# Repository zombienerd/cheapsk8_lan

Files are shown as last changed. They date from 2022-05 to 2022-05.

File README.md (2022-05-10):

CheapSk8 LAN is an 8-bit ISA network card based on the RTL 8019AS chip.  

This project was created for cost savings over purchasing older cards on eBay or building other similar projects.  This project was done by reverse engineering a 16-bit RTL8019AS board, and finding the bits needed in the datasheet to turn off 16 bit mode.

By sourcing the MagJack and RTL8019AS from Aliexpress, the 93LC46 from eBay, and the discretes from Mouser or Digikey, and the PCB from JLCPCB, the bill of materials for a board is only about $7.50 when you build 20 or more.

Link to MagJacks: https://www.aliexpress.com/item/32845892783.html

Link to RTL8019AS: https://www.aliexpress.com/item/4000545658898.html

Link to 93LC46 SMT 1k PROM: https://www.ebay.com/itm/133483822518

Mouser-bom.ods is a spreadsheet for the other discretes needed once you've sourced the above 3 items.

Entire project is licensed under CC BY-SA 4.0: https://creativecommons.org/licenses/by-sa/4.0/  You may copy/modify/distribute this project as you see fit as long as my name and project name are listed, and the license is carried forward to your project.

Drivers / Configuration:

In the Drivers/Config folder, you will find the following software:

NE2000.COM - Modified Crynwr Packet Driver for 8-bit NE2000 based cards.  Modified by Dan over on the VCF Forums (https://forum.vcfed.org/index.php?threads/ne2000-packet-drivers-for-8-bit-slots.41507/)
NE2000.ASM - Associated file to NE2000.COM
PG9018.EXE - Initial programming tool for the card.
8019AS.CFG - Initial Configuration file for the card (Read ahead carefully)
RSET8019.EXE - Configuration tool for the card.

Before configuration, edit 8019AS.CFG and add a MAC address to the 1st line.  If you are building more than one card, you should ensure that no two cards have the same address.  You can use one of the Private MAC address Allocations, known as "Locally Administered Address Ranges" and will not be used by mainstream devices or vendors. The MAC addresses in these ranges can be safely used, as long as they are unique within your network:

x2-xx-xx-xx-xx-xx

x6-xx-xx-xx-xx-xx

xA-xx-xx-xx-xx-xx

xE-xx-xx-xx-xx-xx

Each pair can be any hexadecimal number. You use space instead of - in the cfg file.  For example:  52 0a 1b 3c 4e 5f 00 or 12 1a 2b 3c 4d 5e

You should set your IOBASE to a free IO address (300 is default), IRQ (2 is default), and enable or disable the bootrom.  Beware conflicts with XT-IDE, or certain Sound Card/Midi Devices.  

Once you have edited the file to your liking, boot your machine with no memory managers (EMM386 or HIMEM.sys) and run PG8019.EXE  - this will program the card and tick up the MAC address and serial number incrementally in the 8019as.cfg file, so you don't have to edit to run it on subsequent cards.

Once the card is programmed, you can use RSET8019.EXE at any time to change the Base address and IRQ if you plan to change your system configuration.

Thank you to Sergey Kiselev for hosting the 8019 programming tools that I have copied over for this project.  Check out his very similar project (that's a lot more polished, and a bit more high class) over at https://github.com/skiselev/isa8_eth

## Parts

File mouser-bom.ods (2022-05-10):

SHOPPING CART
This is not an invoice
09-May-22 19:49:48
 | Mouser # | Mfr. # | Manufacturer | Description | Order Qty. | Price (USD) | Ext.: (USD)
1 | 774-ATS200C | ATS200-C | CTS | Crystals 20MHz 18pF Fund. -20C +70C | 20 | $0.30 | $6.00
2 | 77-VJ0603A100JXACBC | VJ0603A100JXACW1BC | Vishay | Multilayer Ceramic Capacitors MLCC - SMD/SMT 0603 10pF 50volts C0G 5% | 40 | $0.046 | $1.84
3 | 77-VJ0603Y103JXACBC | VJ0603Y103JXACW1BC | Vishay | Multilayer Ceramic Capacitors MLCC - SMD/SMT 0603 0.01uF 50volts X7R 5% | 40 | $0.07 | $2.80
4 | 77-VJ0603Y104JXJPBC | VJ0603Y104JXJPW1BC | Vishay | Multilayer Ceramic Capacitors MLCC - SMD/SMT 0603 0.1uF 16volts X7R 5% | 60 | $0.134 | $8.04
5 | 603-RC0603FR-13200RL | RC0603FR-13200RL | YAGEO | Thick Film Resistors - SMD 200Ohms 1/10W 0603 1% | 20 | $0.026 | $0.52
6 | 603-RC0603FR-13470RL | RC0603FR-13470RL | YAGEO | Thick Film Resistors - SMD 470 Ohms 100-200 mW 0603 1% | 40 | $0.017 | $0.68
7 | 603-RC0603FR-1327KL | RC0603FR-1327KL | YAGEO | Thick Film Resistors - SMD 27 kOhms 100-200 mW 0603 1% | 20 | $0.018 | $0.36
8 | 603-RC0603FR-101ML | RC0603FR-101ML | YAGEO | Thick Film Resistors - SMD 1 MOhms 100-200 mW 0603 1% | 20 | $0.018 | $0.36
9 | 710-860010472003 | 860010472003 | Wurth Elektronik | Aluminum Electrolytic Capacitors - Radial Leaded WCAP-ATG8 22uF 25V 20% Radial | 40 | $0.10 | $4.00
10 | 667-ERJ-3GEYJ103V | ERJ-3GEYJ103V | Panasonic | Thick Film Resistors - SMD 0603 10Kohms 5% AEC-Q200 | 20 | $0.044 | $0.88
By submitting your order you agree to these terms and conditions. (https://www.mouser.com/saleterms) |  |  |  |  |  | Merchandise: | $25.48
Prices are reflected at the date and time shown.

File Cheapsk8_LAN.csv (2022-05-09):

Source: | /home/yestergearpc/cheapsk8_lan/Cheapsk8_LAN.kicad_sch
Date: | Mon 09 May 2022 02:30:59 PM EDT
Tool: | Eeschema 6.0.2+dfsg-1
Generator: | /usr/share/kicad/plugins/bom_csv_grouped_by_value_with_fp.py
Component Count: | 21
Ref | Qnty | Value | Cmp name | Footprint | Description | Vendor
C1, | 1 | 0.1uf | C | Capacitor_SMD:C_0201_0603Metric_Pad0.64x0.40mm_HandSolder | Unpolarized capacitor
C2, C3, | 2 | 0.1uF | C | Capacitor_SMD:C_0201_0603Metric_Pad0.64x0.40mm_HandSolder | Unpolarized capacitor
C4, C5, | 2 | 10pF | C | Capacitor_SMD:C_0201_0603Metric_Pad0.64x0.40mm_HandSolder | Unpolarized capacitor
C6, C7, | 2 | 22uF | C_Polarized_Small_US | Capacitor_THT:CP_Radial_D5.0mm_P2.00mm | Polarized capacitor, small US symbol
C8, C9, | 2 | 0.01uF | C | Capacitor_SMD:C_0201_0603Metric_Pad0.64x0.40mm_HandSolder | Unpolarized capacitor
J2, | 1 | Bus_ISA_8bit | Bus_ISA_8bit | ISABUS:BUS_PC | 8-bit ISA-PC bus connector
J3, | 1 | SI-50170-F | SI-50170-F | ISABUS:BEL_SI-50170-F
R14, | 1 | 27k | R | Resistor_SMD:R_0603_1608Metric_Pad0.98x0.95mm_HandSolder | Resistor
R15, | 1 | 10k | R | Resistor_SMD:R_0603_1608Metric_Pad0.98x0.95mm_HandSolder | Resistor
R16, R17, | 2 | 470 | R | Resistor_SMD:R_0603_1608Metric_Pad0.98x0.95mm_HandSolder | Resistor
R18, | 1 | 200 | R | Resistor_SMD:R_0603_1608Metric_Pad0.98x0.95mm_HandSolder | Resistor
R19, | 1 | 1M | R | Resistor_SMD:R_0603_1608Metric_Pad0.98x0.95mm_HandSolder | Resistor
U1, | 1 | RTL8019AS | RTL8019AS | ISABUS:RTL8019AS
U2, | 1 | SST39SF040 | SST39SF040 | Package_DIP:DIP-32_W15.24mm | Silicon Storage Technology (SSF) 512k x 8 Flash ROM
U3, | 1 | 93LCxxC | 93LCxxC | Package_DIP:DIP-8_W7.62mm_SMDSocket_SmallPads | Serial EEPROM, 93 Series, with ORG Pin, 2.5V, DIP-8/SOIC-8
Y1, | 1 | 20MHz | Crystal | Crystal:Crystal_HC49-U_Horizontal | Two pin crystal

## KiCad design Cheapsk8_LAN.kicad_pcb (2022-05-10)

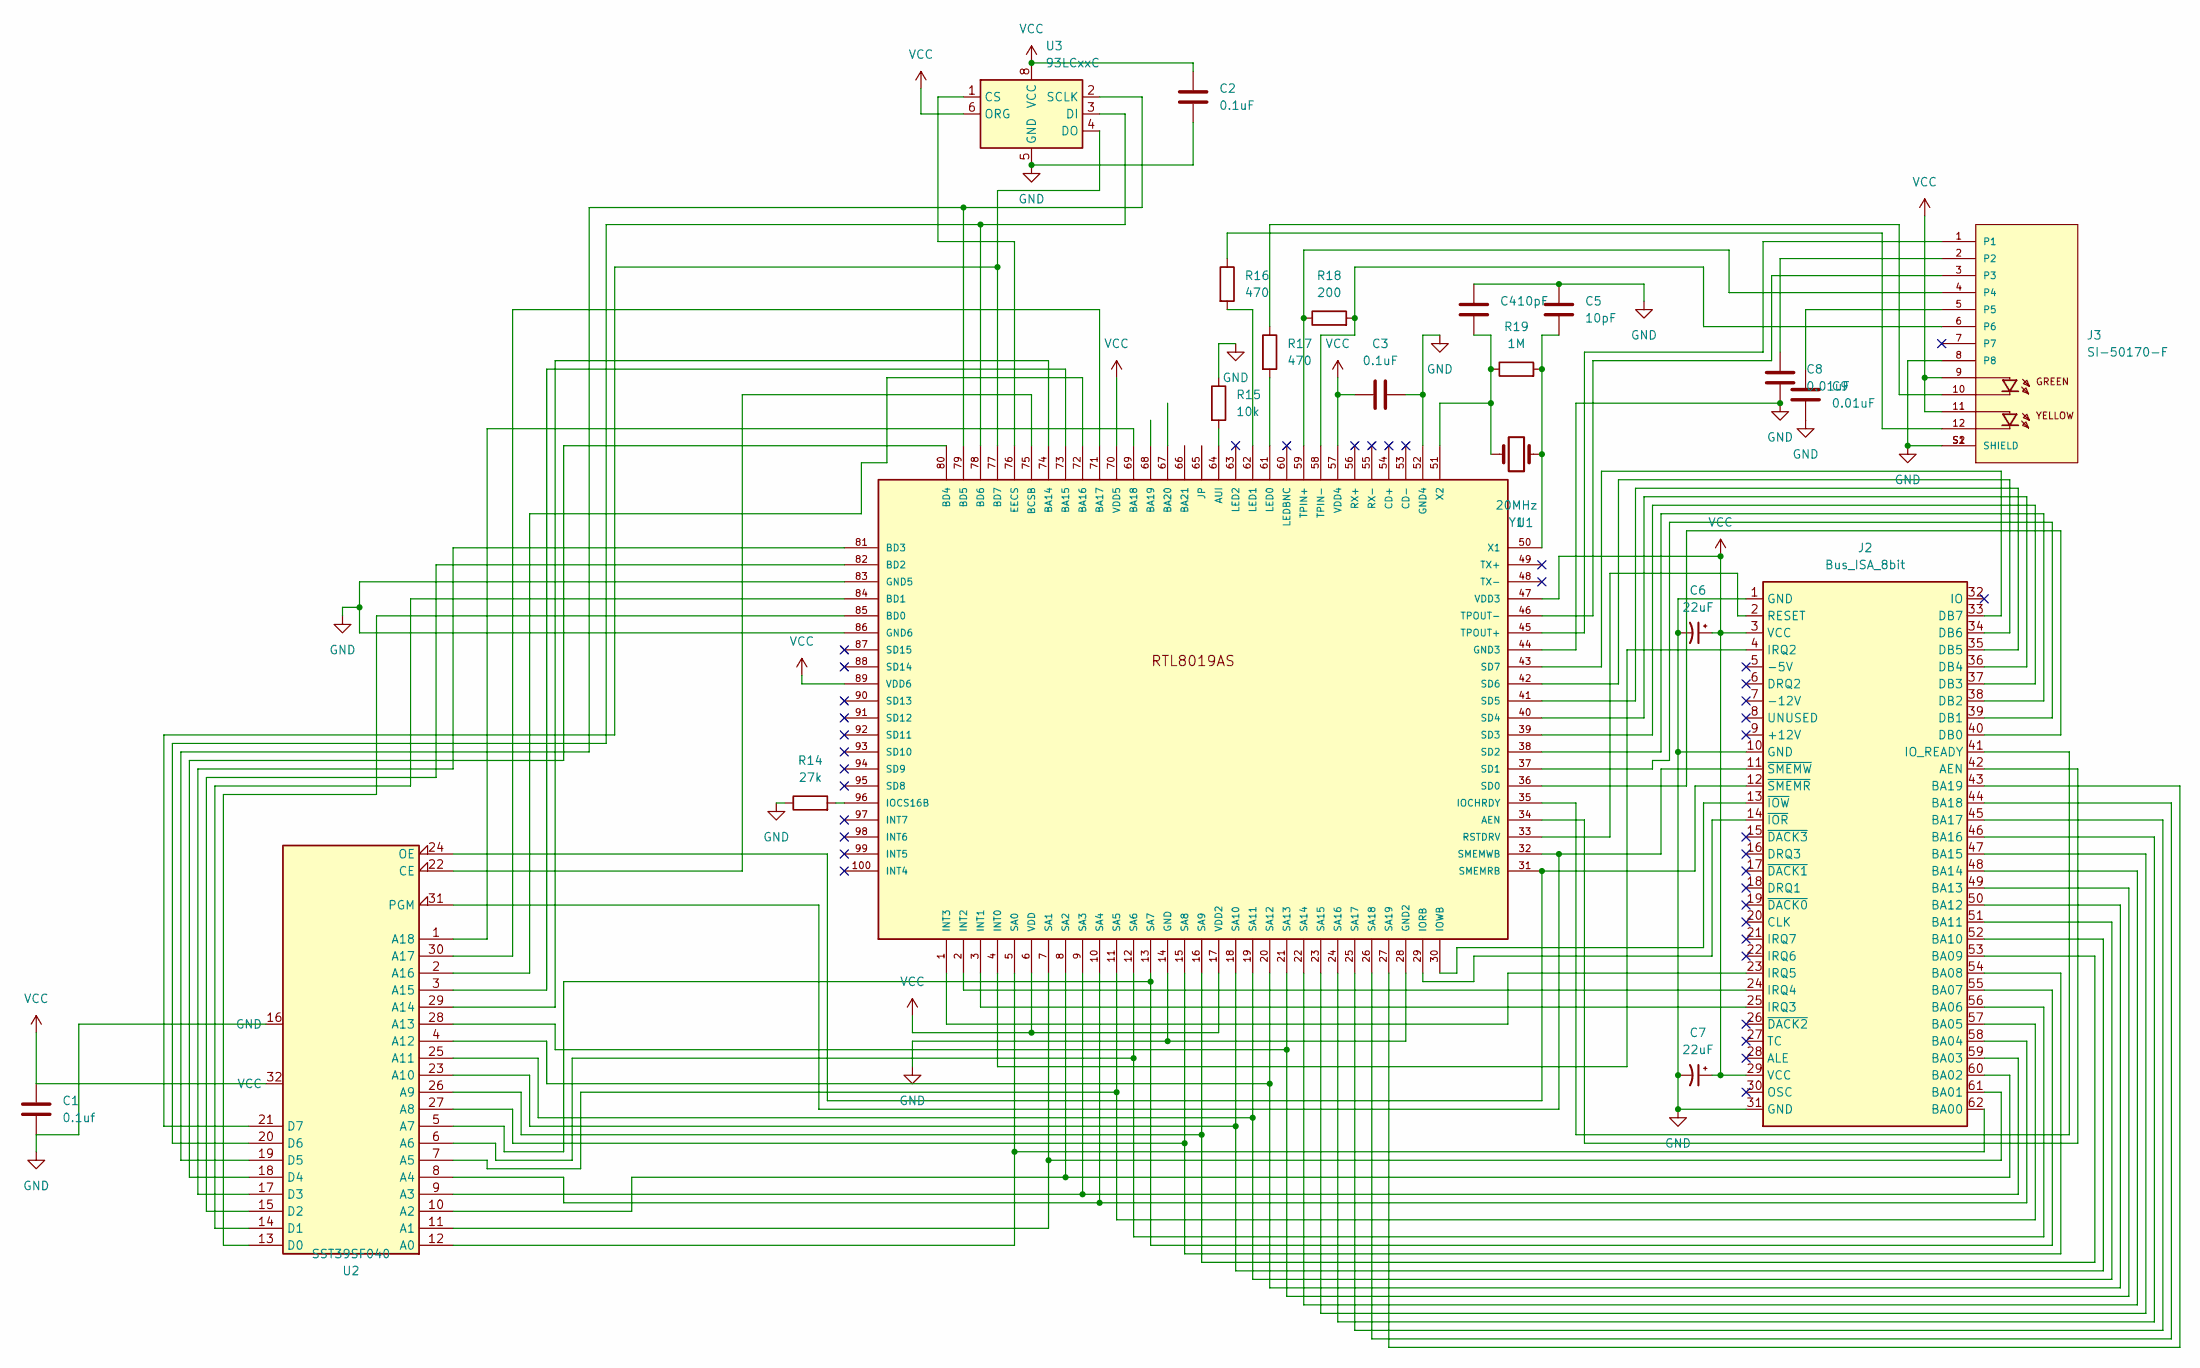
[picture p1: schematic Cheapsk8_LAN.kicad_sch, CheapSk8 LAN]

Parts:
C1: 0.1uf; C_0201_0603Metric_Pad0.64x0.40mm_HandSolder
C2, C3: 0.1uF; C_0201_0603Metric_Pad0.64x0.40mm_HandSolder
C4, C5: 10pF; C_0201_0603Metric_Pad0.64x0.40mm_HandSolder
C6, C7: 22uF; CP_Radial_D5.0mm_P2.00mm
C8, C9: 0.01uF; C_0201_0603Metric_Pad0.64x0.40mm_HandSolder
J2: Bus_ISA_8bit; BUS_PC
J3: SI-50170-F; BEL_SI-50170-F; PARTREV 07
R14: 27k; R_0603_1608Metric_Pad0.98x0.95mm_HandSolder
R15: 10k; R_0603_1608Metric_Pad0.98x0.95mm_HandSolder
R16, R17: 470; R_0603_1608Metric_Pad0.98x0.95mm_HandSolder
R18: 200; R_0603_1608Metric_Pad0.98x0.95mm_HandSolder
R19: 1M; R_0603_1608Metric_Pad0.98x0.95mm_HandSolder
U1: RTL8019AS
U2: SST39SF040; DIP-32_W15.24mm
U3: 93LCxxC; DIP-8_W7.62mm_SMDSocket_SmallPads
Y1: 20MHz; Crystal_HC49-U_Horizontal

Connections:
GND: C1.2, C2.2, C3.2, C4.1, C5.1, C6.2, C7.2, C8.2, C9.2, J2.1 (GND), J2.10 (GND), J2.31 (GND), J3.8, J3.S1 (SHIELD), J3.S2 (SHIELD), R14.1, R15.1, U1.14 (GND), U1.28 (GND2), U1.44 (GND3), U1.52 (GND4), U1.83 (GND5), U1.86 (GND6), U2.16 (GND), U3.5 (GND)
unnamed: C8.1, J3.2
unnamed: C9.1, J3.5
unnamed: J3.10, R17.1
unnamed: J3.12, R16.1
unnamed: J2.23 (IRQ5), U1.1 (INT3)
unnamed: J2.24 (IRQ4), U1.2 (INT2)
unnamed: J2.25 (IRQ3), U1.3 (INT1)
unnamed: J2.4 (IRQ2), U1.4 (INT0)
unnamed: J2.62 (BA00), U1.5 (SA0), U2.12 (A0)
unnamed: J2.61 (BA01), U1.7 (SA1), U2.11 (A1)
unnamed: J2.60 (BA02), U1.8 (SA2), U2.10 (A2)
unnamed: J2.59 (BA03), U1.9 (SA3), U2.9 (A3)
unnamed: J2.58 (BA04), U1.10 (SA4), U2.8 (A4)
unnamed: J2.57 (BA05), U1.11 (SA5), U2.7 (A5)
unnamed: J2.56 (BA06), U1.12 (SA6), U2.6 (A6)
unnamed: J2.55 (BA07), U1.13 (SA7), U2.5 (A7)
unnamed: J2.54 (BA08), U1.15 (SA8), U2.27 (A8)
unnamed: J2.53 (BA09), U1.16 (SA9), U2.26 (A9)
unnamed: J2.52 (BA10), U1.18 (SA10), U2.23 (A10)
unnamed: J2.51 (BA11), U1.19 (SA11), U2.25 (A11)
unnamed: J2.50 (BA12), U1.20 (SA12), U2.4 (A12)
unnamed: J2.49 (BA13), U1.21 (SA13), U2.28 (A13)
unnamed: J2.48 (BA14), U1.22 (SA14)
unnamed: J2.47 (BA15), U1.23 (SA15)
unnamed: J2.46 (BA16), U1.24 (SA16)
unnamed: J2.45 (BA17), U1.25 (SA17)
unnamed: J2.44 (BA18), U1.26 (SA18)
unnamed: J2.43 (BA19), U1.27 (SA19)
unnamed: J2.14 (~IOR), U1.29 (IORB)
unnamed: J2.13 (~IOW), U1.30 (IOWB)
unnamed: J2.12 (~SMEMR), U1.31 (SMEMRB), U2.24 (OE)
unnamed: J2.11 (~SMEMW), U1.32 (SMEMWB), U2.31 (PGM)
unnamed: J2.2 (RESET), U1.33 (RSTDRV)
unnamed: J2.42 (AEN), U1.34 (AEN)
unnamed: J2.41 (IO_READY), U1.35 (IOCHRDY)
unnamed: J2.40 (DB0), U1.36 (SD0)
unnamed: J2.39 (DB1), U1.37 (SD1)
unnamed: J2.38 (DB2), U1.38 (SD2)
unnamed: J2.37 (DB3), U1.39 (SD3)
unnamed: J2.36 (DB4), U1.40 (SD4)
unnamed: J2.35 (DB5), U1.41 (SD5)
unnamed: J2.34 (DB6), U1.42 (SD6)
unnamed: J2.33 (DB7), U1.43 (SD7)
unnamed: J3.1, U1.45 (TPOUT+)
unnamed: J3.3, U1.46 (TPOUT-)
unnamed: C5.2, R19.2, U1.50 (X1), Y1.1
unnamed: C4.2, R19.1, U1.51 (X2), Y1.2
unnamed: J3.6, R18.2, U1.58 (TPIN-)
unnamed: J3.4, R18.1, U1.59 (TPIN+)
unnamed: R17.2, U1.61 (LED0)
unnamed: R16.2, U1.62 (LED1)
unnamed: R15.2, U1.64 (AUI)
unnamed: U1.69 (BA18), U2.1 (A18)
unnamed: U1.71 (BA17), U2.30 (A17)
unnamed: U1.72 (BA16), U2.2 (A16)
unnamed: U1.73 (BA15), U2.3 (A15)
unnamed: U1.74 (BA14), U2.29 (A14)
unnamed: U1.75 (BCSB), U2.22 (CE)
unnamed: U1.76 (EECS), U3.1 (CS)
unnamed: U1.77 (BD7), U2.21 (D7), U3.4 (DO)
unnamed: U1.78 (BD6), U2.20 (D6), U3.3 (DI)
unnamed: U1.79 (BD5), U2.19 (D5), U3.2 (SCLK)
unnamed: U1.80 (BD4), U2.18 (D4)
unnamed: U1.81 (BD3), U2.17 (D3)
unnamed: U1.82 (BD2), U2.15 (D2)
unnamed: U1.84 (BD1), U2.14 (D1)
unnamed: U1.85 (BD0), U2.13 (D0)
unnamed: R14.2, U1.96 (IOCS16B)
VCC: C1.1, C2.1, C3.1, C6.1, C7.1, J2.3 (VCC), J2.29 (VCC), J3.9, J3.11, U1.6 (VDD), U1.17 (VDD2), U1.47 (VDD3), U1.57 (VDD4), U1.70 (VDD5), U1.89 (VDD6), U2.32 (VCC), U3.6 (ORG), U3.8 (VCC)

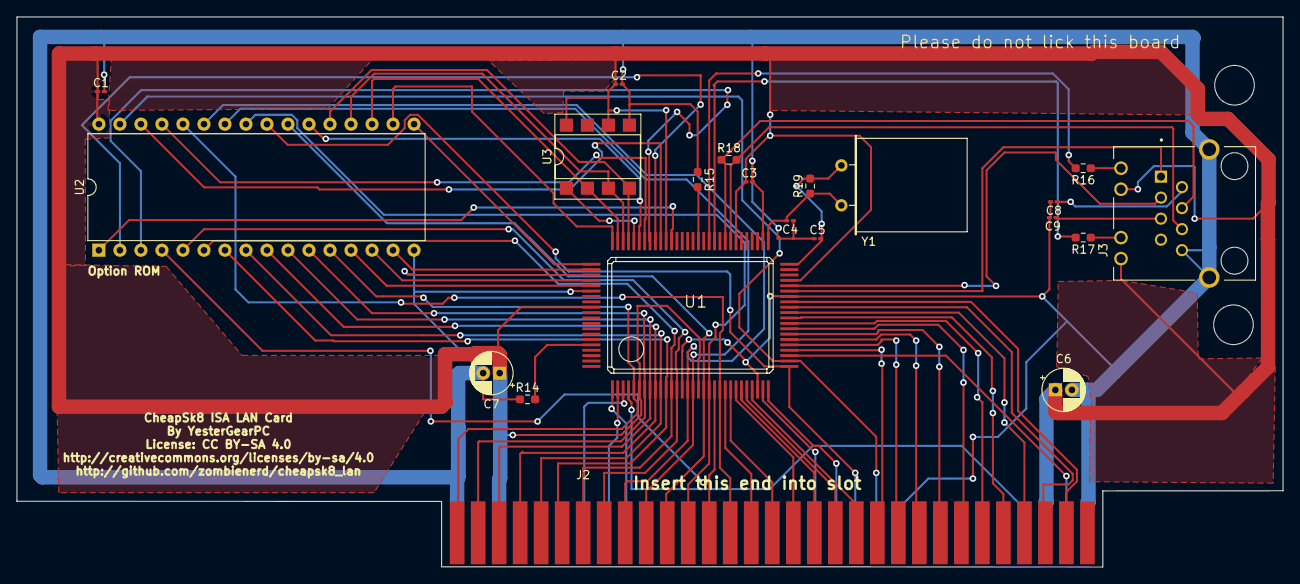
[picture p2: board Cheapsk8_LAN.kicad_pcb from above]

Board: 2 copper layers, 153.1 x 66.5 mm, 21 parts (0 on the bottom side), 70 nets.

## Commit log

2022-05-09 Changes to be committed: modified: Cheapsk8_LAN.kicad_pcb modified: Cheapsk8_LAN.kicad_prl modified: Cheapsk8_LAN.kicad_pro modified: Cheapsk8_LAN.kicad_sch
    Untracked files:
    Cheapsk8_LAN.csv
    Cheapsk8_LAN.net
    Cheapsk8_LAN.xml
    fp-info-cache
    fp-lib-table
    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
    [Cheapsk8_LAN.kicad_pcb, Cheapsk8_LAN.kicad_sch]
2022-05-09 new file: Cheapsk8_LAN.csv new file: Cheapsk8_LAN.net new file: Cheapsk8_LAN.xml new file: gerber/Cheapsk8_LAN-B_Cu.gbr new file: gerber/Cheapsk8_LAN-B_Mask.gbr new file: gerber/Cheapsk8_LAN-B_Paste.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
    [Cheapsk8_LAN-B_Cu.gbr, Cheapsk8_LAN-B_Mask.gbr, Cheapsk8_LAN-B_Paste.gbr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]
2022-05-10 new file: drivers-config/8019AS.CFG new file: drivers-config/8019AS.CFG.ORIG new file: drivers-config/COPYING.DOC new file: drivers-config/NE2000.ASM new file: drivers-config/NE2000.COM new file: dri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
    [8019AS.CFG]
2022-05-10 modified: drivers-config/8019AS.CFG deleted: drivers-config/8019AS.CFG.ORIG deleted: drivers-config/COPYING.DOC
    [8019AS.CFG]
2022-05-10 modified: drivers-config/8019AS.CFG
    [8019AS.CFG]
2022-05-10 new file: mouser-bom.ods
    [mouser-bom.ods]
2022-05-10 modified: Cheapsk8_LAN.kicad_pcb modified: Cheapsk8_LAN.kicad_prl modified: gerber/Cheapsk8_LAN-B_Cu.gbr modified: gerber/Cheapsk8_LAN-B_Mask.gbr modified: gerber/Cheapsk8_LAN-B_Paste.gbr modified: g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
    [Cheapsk8_LAN-B_Cu.gbr, Cheapsk8_LAN-B_Mask.gbr, Cheapsk8_LAN-B_Paste.gbr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]
2022-05-12 modified: gerber/Cheapsk8_LAN-B_Cu.gbr modified: gerber/Cheapsk8_LAN-B_Mask.gbr modified: gerber/Cheapsk8_LAN-B_Paste.gbr modified: gerber/Cheapsk8_LAN-B_Silkscreen.gbr modified: gerber/Cheapsk8_LAN-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
    [Cheapsk8_LAN-B_Cu.gbr, Cheapsk8_LAN-B_Mask.gbr, Cheapsk8_LAN-B_Paste.gbr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]

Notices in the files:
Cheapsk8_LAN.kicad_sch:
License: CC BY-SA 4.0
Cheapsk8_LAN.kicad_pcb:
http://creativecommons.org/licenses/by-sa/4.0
